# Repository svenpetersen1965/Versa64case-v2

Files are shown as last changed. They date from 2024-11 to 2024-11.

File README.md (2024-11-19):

# Versa64case-v2
The Versa64case v2 is my 2nd approach to a 3D printed case for the <a href="https://github.com/bwack/Versa64Cart">Versa64card by bwack</a>. 

The goal was to develope a case, that is less complicated than the first case from 2019 and only consist of two parts while offering fill access to the DIP-switch and the configuration jumpers. Also, a closed version without this access is required, in case no configuration change is desired or for the <a href="https://github.com/svenpetersen1965/Epyx-FastLoad">Epxy Fast Load cartridge</a>.

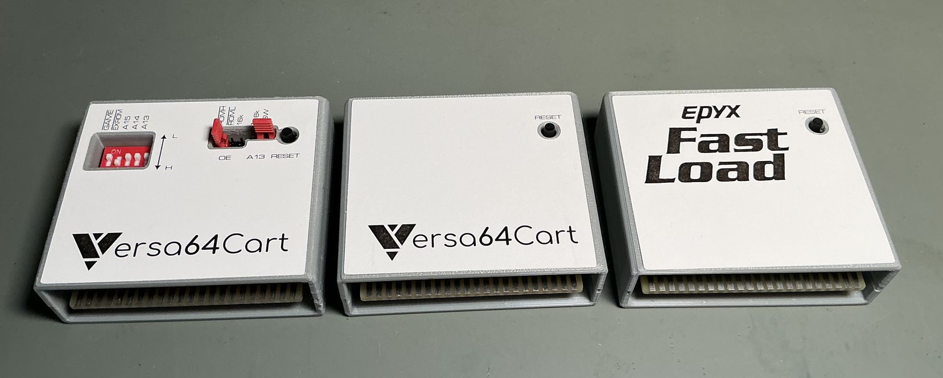
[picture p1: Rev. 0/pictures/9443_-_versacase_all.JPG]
Versa64case


# Versions

1. <b>Versa64case With Full Configuration Access</b><br>
This version allows to access the DIP-switch and the configuration jumpers.

2. <b>Versa64case Without Configuration Access</b><br>
This version does not allow changing the configuration of the Versa64cart without opening the case, which might be a desirable option for some projects.

# Project Documentation

Please consider reading the <a href="https://github.com/svenpetersen1965/Versa64case-v2/blob/main/Rev.%200/pdf/Versa64caseV2_Rev0.pdf">Documentation</a>.

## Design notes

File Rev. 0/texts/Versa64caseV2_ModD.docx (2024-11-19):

Versa64case v2 Rev. 0

Module description

# 1. Introduction

The Versa64case v2 is my 2nd approach to a 3D printed case for the Versa64card by bwack. The Versa64cart can be found here: https://github.com/bwack/Versa64Cart

The goal was to develop a case, that is less complicated than the first case from 2019 and only consist of two parts while offering fill access to the DIP-switch and the configuration jumpers. Also, a closed version without this access is required, in case no configuration change is desired or for the Epxy Fast Load cartridge (which can be found here: https://github.com/svenpetersen1965/Epyx-FastLoad).


Figure 1: All versions of the case with labels

# 2. Versa64case With Full Configuration Access

This version allows to access the DIP-switch and the configuration jumpers. For the easiest way to change the configuration, it is best to use jumpers with a “handle”, which protrude over the case. They are available from multiple sources and manufacturers (e.g. Reichelt MPE 149-4-002-F0 or Ali Express product URL (https://de.aliexpress.com/item/1005006390258256.html?channel=twinner)).

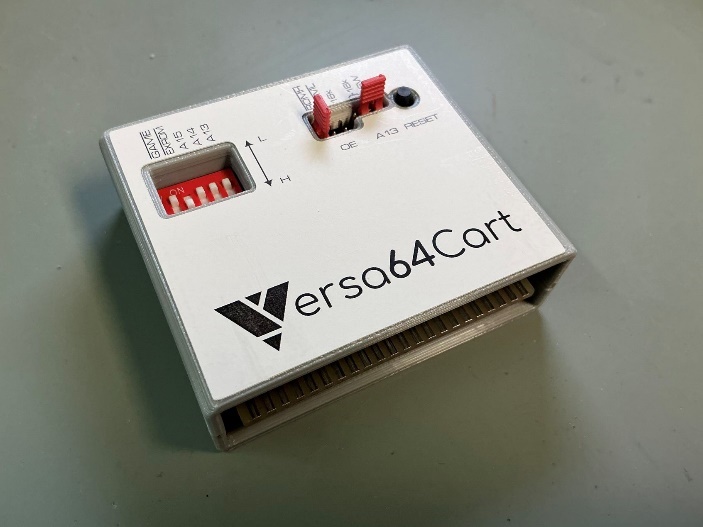
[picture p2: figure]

Figure 2: Version with full configuration access

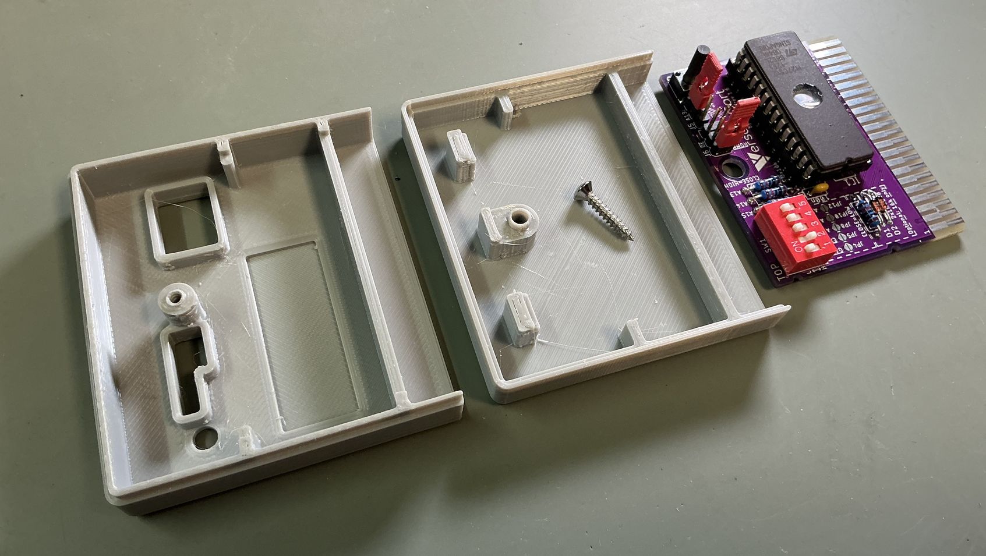
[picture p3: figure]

Figure 3: Version with full configuration access (internal)

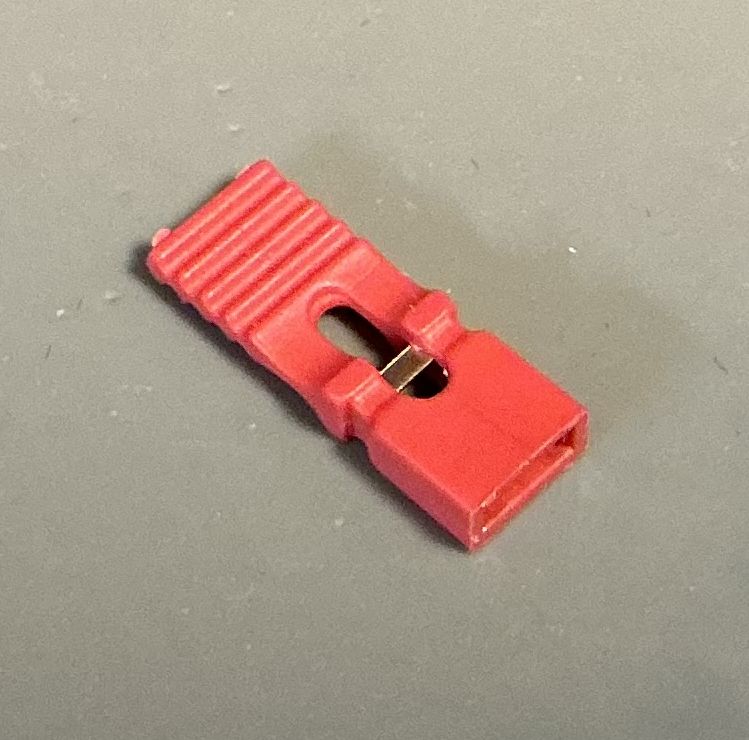
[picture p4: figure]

Figure 4: Jumper with handle

# 3. Versa64case Without Configuration Access

This version does not allow changing the configuration of the Versa64cart without opening the case, which might be a desirable option for some projects.

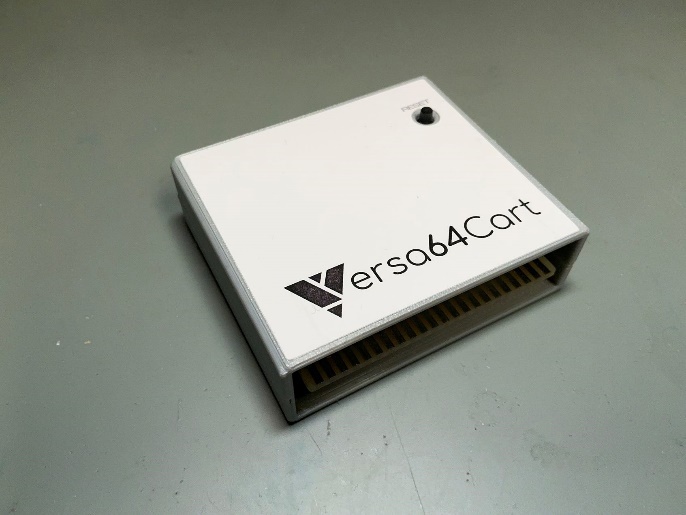
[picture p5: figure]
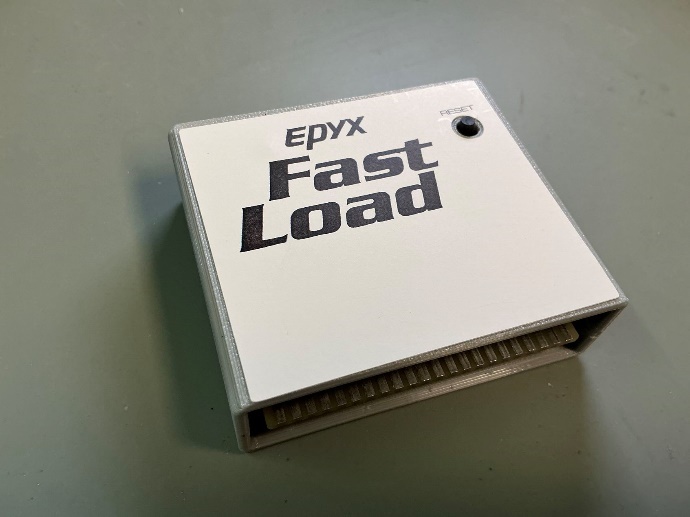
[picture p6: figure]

Figure 5: Versa64Case without configuration access

The Epyx FastLoad cartridge, which was mentioned before, does not require accessing any configuration and has the same form factor of the Versa64Cart. There is an extra version of label for it.

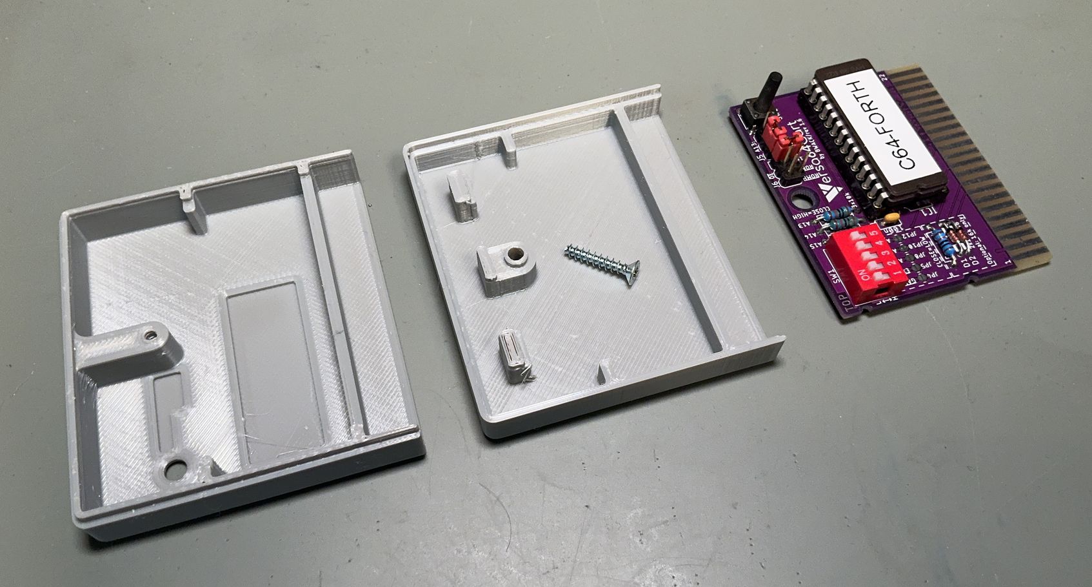
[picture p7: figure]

Figure 6: Closed version without configuration access

In case short pin headers and (open) jumpers are used, they will fit under the case.

# 4. The Reset Switch

Originally, the reset switch on the Versa64card has a height of 7mm. For this case a TACT switch with a total height of 11.0mm -12.5mm is recommended. The distance between the top surface of the case and the top surface of the PCB is 10.8 mm.

# 5. Recommended screws

Countersunk, self-tapping screws with a total length of 13.0mm to 16.0mm and a diameter of 2.9mm (C2.9 x 13 or C2.9 x 16) are recommended. E.g. DIN 7982 or DIN 7983.

# 6. Revision History

## 6.1. Rev. 0

- Working prototype

Versa64caseV2_ModD.docx 19.11.2024 17:24 Drafted by Sven Petersen Page 2 of 2 Doc.-No.: 216-6-01-00

Versa64caseV2_ModD.docx 19.11.2024 17:24 Drafted by Sven Petersen Page 1 of 1 Doc.-No.: 216-6-01-00

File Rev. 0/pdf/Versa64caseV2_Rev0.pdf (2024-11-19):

# Project Documentation

## Versa64case v2

## Project number: 216

## Revision: 0

## Date: 19.11.2024

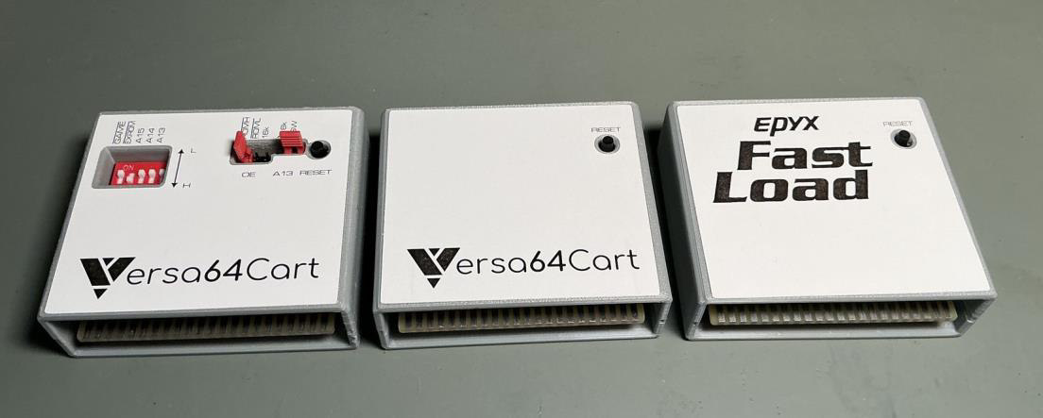
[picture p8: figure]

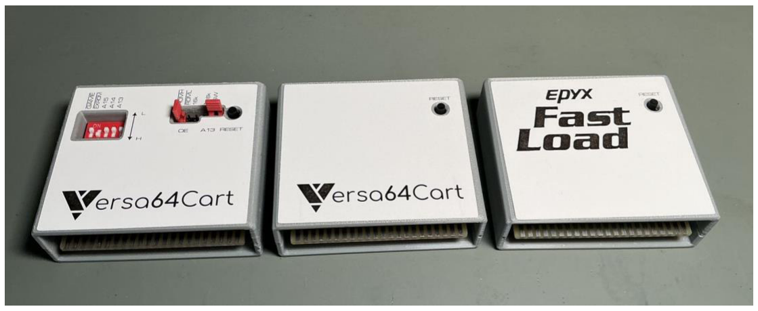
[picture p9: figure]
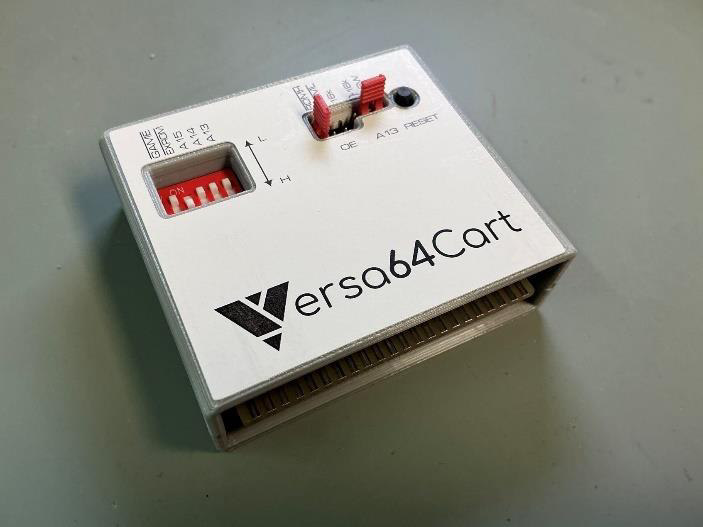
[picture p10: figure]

Versa64caseV2_ModD.docx | | 19.11.2024 17:24
Drafted by Sven Petersen | Page 1 of 4 | Doc.-No.: 216-6-01-00

### Versa64case v2 Rev. 0

### Module description

## 1. Introduction

The Versa64case v2 is my 2nd approach to a 3D printed case for the Versa64card by bwack. The Versa64cart can be found here: https://github.com/bwack/Versa64Cart

The goal was to develop a case, that is less complicated than the first case from 2019 and only consist of two parts while offering fill access to the DIP-switch and the configuration jumpers. Also, a closed version without this access is required, in case no configuration change is desired
or | for | the | Epxy | Fast | Load | cartridge | (which | can | be | found | here:
https://github.com/svenpetersen1965/Epyx-FastLoad).

Figure 1: All versions of the case with labels

## 2. Versa64case With Full Configuration Access

This version allows to access the DIP-switch and the configuration jumpers. For the easiest way to change the configuration, it is best to use jumpers with a “handle”, which protrude over the case. They are available from multiple sources and manufacturers (e.g. Reichelt MPE 149-4-002-F0 or Ali Express product URL). (https://de.aliexpress.com/item/1005006390258256.html?channel=twinner)

Figure 2: Version with full configuration access

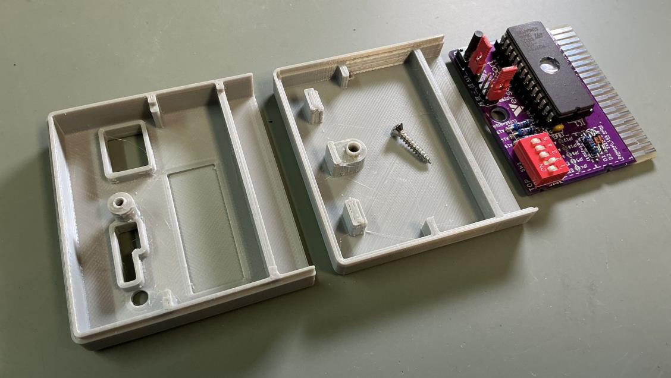
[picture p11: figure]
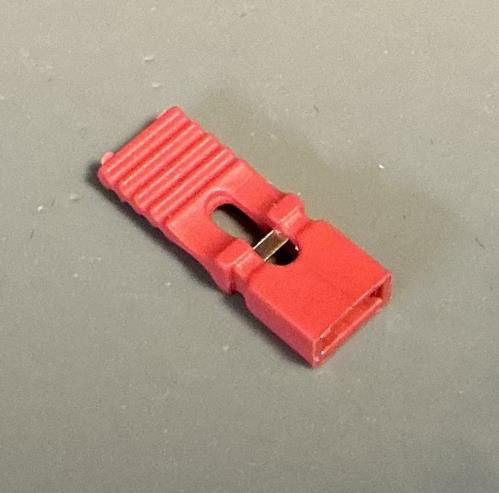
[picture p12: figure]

Drafted by Sven Petersen | Page 2 of 4 | Doc.-No.: 216-6-01-00

Figure 3: Version with full configuration access (internal)

Figure 4: Jumper with handle

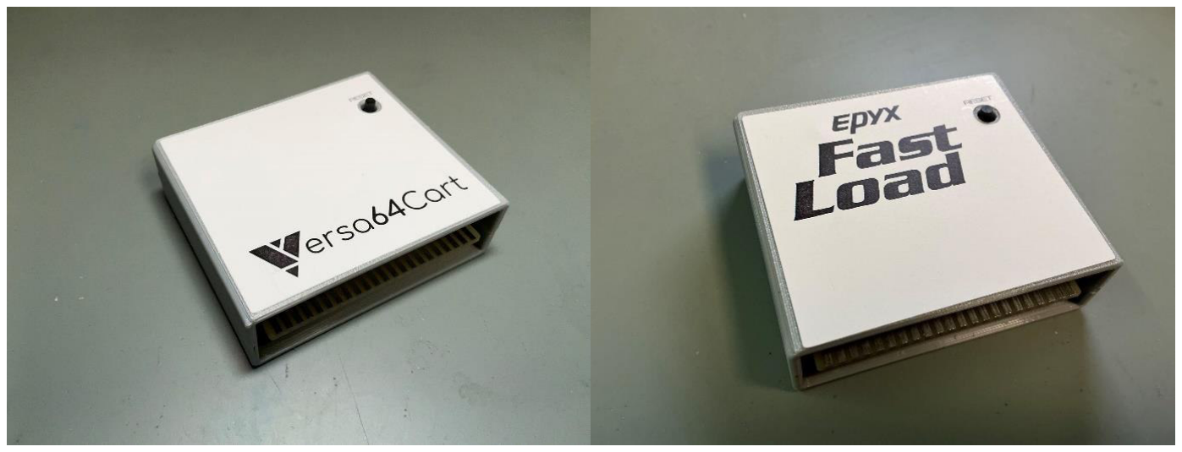
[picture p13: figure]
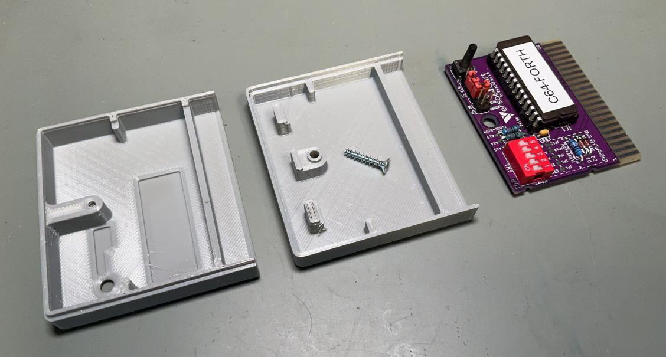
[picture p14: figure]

Drafted by Sven Petersen | Page 3 of 4 | Doc.-No.: 216-6-01-00

## 3. Versa64case Without Configuration Access

This version does not allow changing the configuration of the Versa64cart without opening the case, which might be a desirable option for some projects.

Figure 5: Versa64Case without configuration access

The Epyx FastLoad cartridge, which was mentioned before, does not require accessing any configuration and has the same form factor of the Versa64Cart. There is an extra version of label for it.

Figure 6: Closed version without configuration access

In case short pin headers and (open) jumpers are used, they will fit under the case.

## 4. The Reset Switch

Originally, the reset switch on the Versa64card has a height of 7mm. For this case a TACT switch with a total height of 11.0mm -12.5mm is recommended. The distance between the top surface of the case and the top surface of the PCB is 10.8 mm.

## 5. Recommended screws

Countersunk, self-tapping screws with a total length of 13.0mm to 16.0mm and a diameter of 2.9mm (C2.9 x 13 or C2.9 x 16) are recommended. E.g. DIN 7982 or DIN 7983.

Drafted by Sven Petersen | Page 4 of 4 | Doc.-No.: 216-6-01-00

## 6. Revision History

### 6.1. Rev. 0

- Working prototype

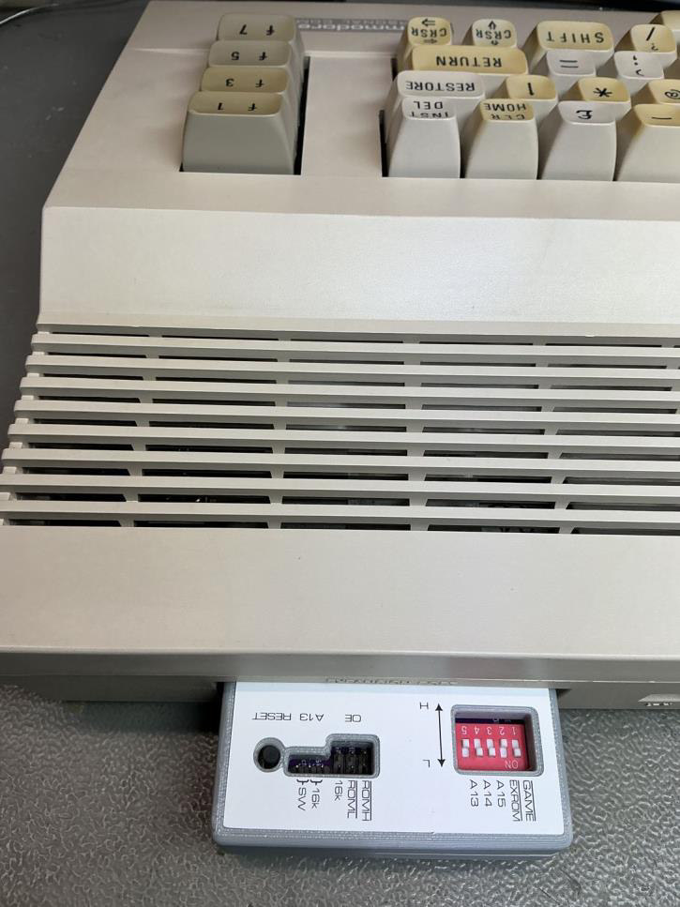
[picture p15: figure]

Versa64caseV2_Test.docx | | 19.11.2024 19:34
Drafted by Sven Petersen | Page 1 of 3 | Doc.-No.: 216-6-02-00

### Versa64case v2 Rev. 0

### Test Description description

## 1. Devices under Test

- Versa64case v2 with accessible configuration with Versa64Cart and long jumpers
- Versa64case v2 without accessible configuration with Versa64Cart and short jumpers
- Versa64case v2 without accessible configuration with Epyx Fast Load

## 2. Test Execution

### 2.1. Mountability

- Both, the Versa64cart and the Epyx FastLoad cartridge PCBs fit inside the cases.
- The short jumpers do not collide with the top shell
- The screw (16mm and 13mm) fits into the case and reliably holds both halves together

### 2.2. Fits into the Expansion Ports

Both versions of the case are tested with different computers

- The cases fit into the expansion port of the C64 bread bin (Figure 3)
- The cases fit into the expansion port of the C64C (Figure 2)
- The cases fit into the expansion port of the C128 (Figure 1)

Figure 1: Test with C128

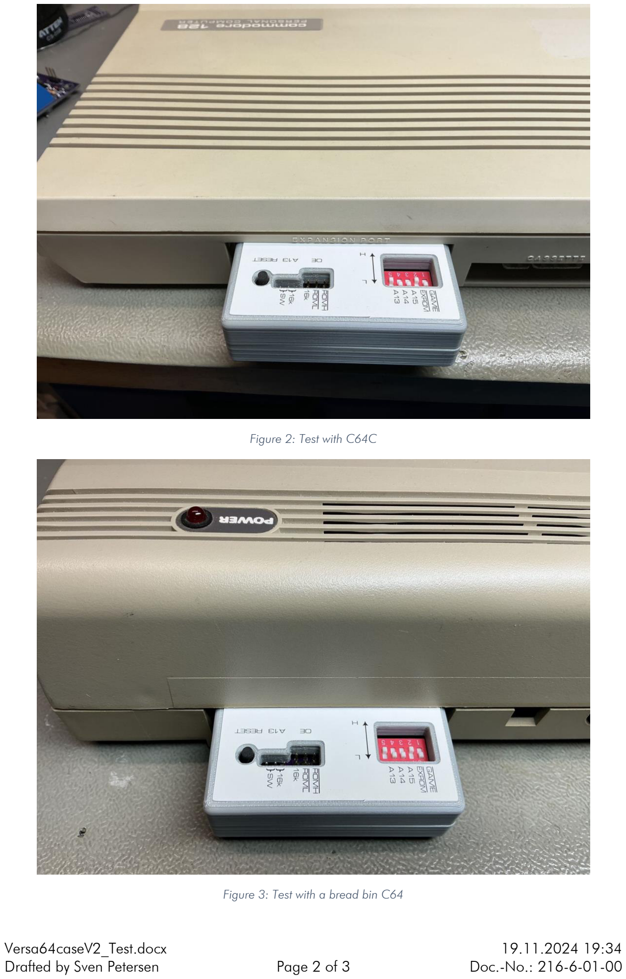
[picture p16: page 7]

Versa64caseV2_Test.docx | | 19.11.2024 19:34
Drafted by Sven Petersen | Page 2 of 3 | Doc.-No.: 216-6-01-00

Figure 2: Test with C64C

Figure 3: Test with a bread bin C64

Versa64caseV2_Test.docx | | 19.11.2024 19:34
Drafted by Sven Petersen | Page 3 of 3 | Doc.-No.: 216-6-01-00

## Conclusion

The Versa63case v2 works/fits with all known configuration.

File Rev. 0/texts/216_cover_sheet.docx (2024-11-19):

Project Documentation

Versa64case v2

Project number: 216

Revision: 0

Date: 19.11.2024


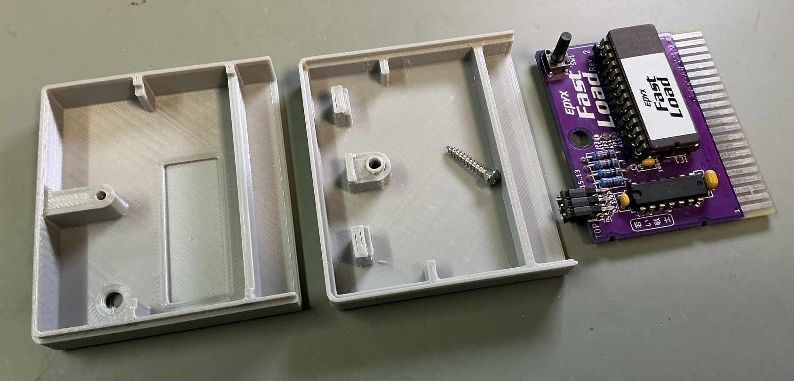
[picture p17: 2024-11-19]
Rev. 0/pictures/9254_-_versacase_no_acc_EpyxFL.JPG

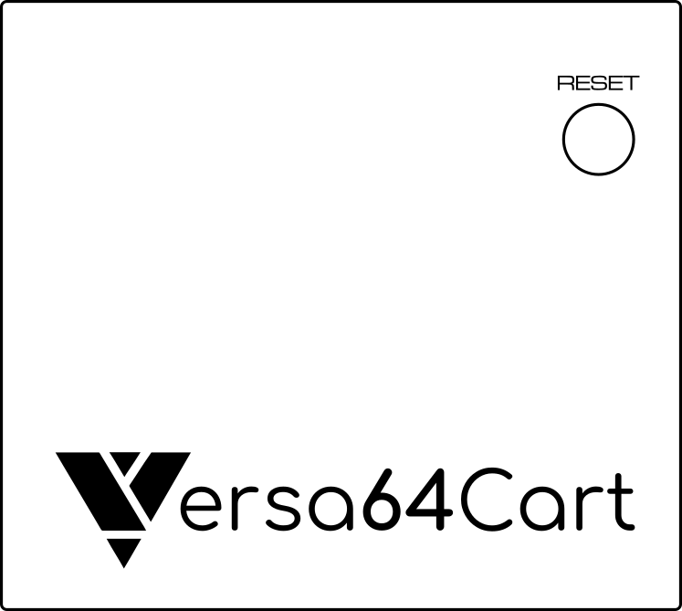
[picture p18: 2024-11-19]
Rev. 0/label/Versa64case_closed_label.png

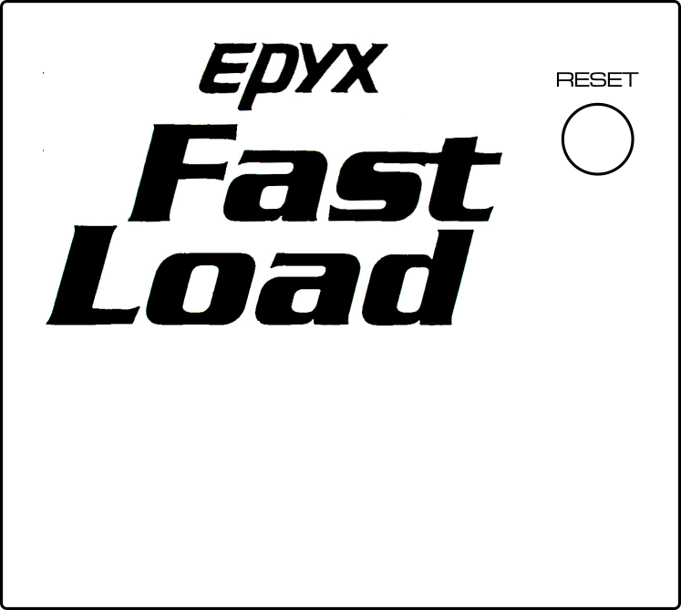
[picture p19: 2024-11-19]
Rev. 0/label/Versa64case_Epyx_FastLoad_label.png

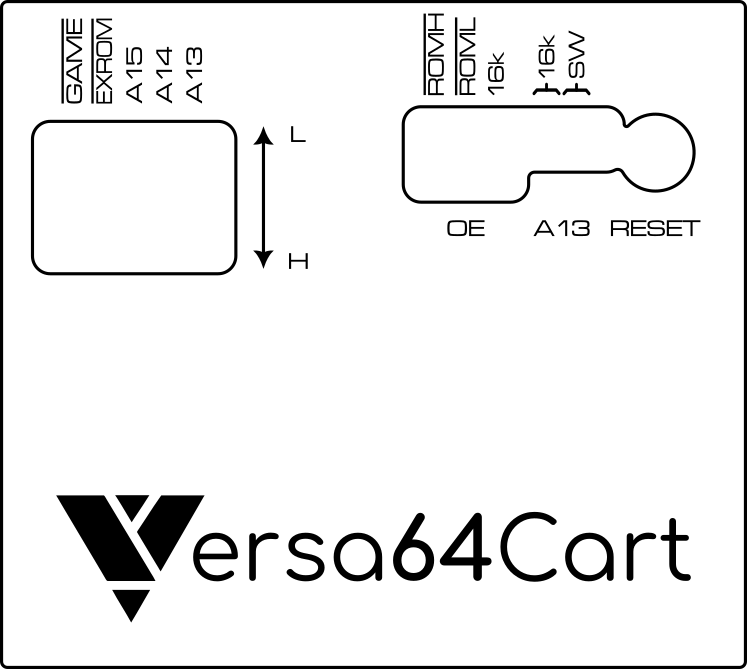
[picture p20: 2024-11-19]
Rev. 0/label/Versa64case_label.png

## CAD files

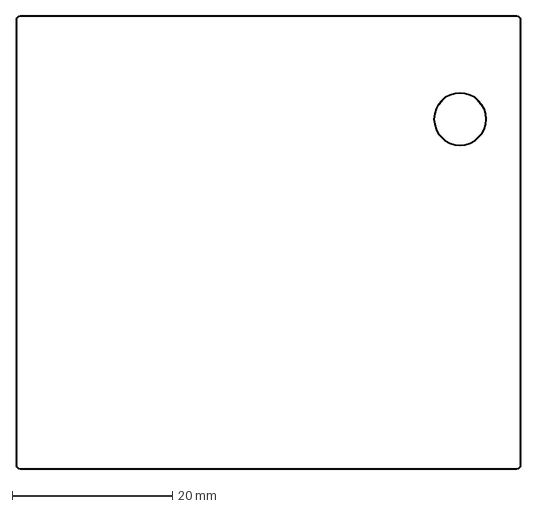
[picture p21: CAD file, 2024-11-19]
Rev. 0/label/outline_closed.dxf
63.0 x 56.4 mm

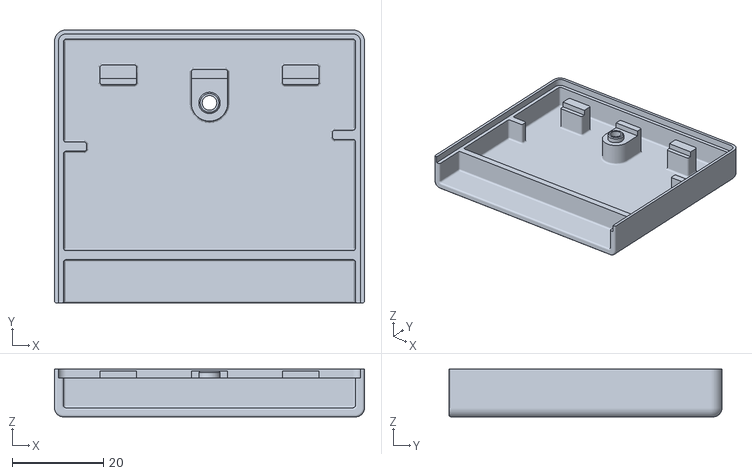
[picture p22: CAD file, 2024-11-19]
Rev. 0/stl/versa64case_v2_bottom_closed.stl
68.0 x 59.9 x 10.5

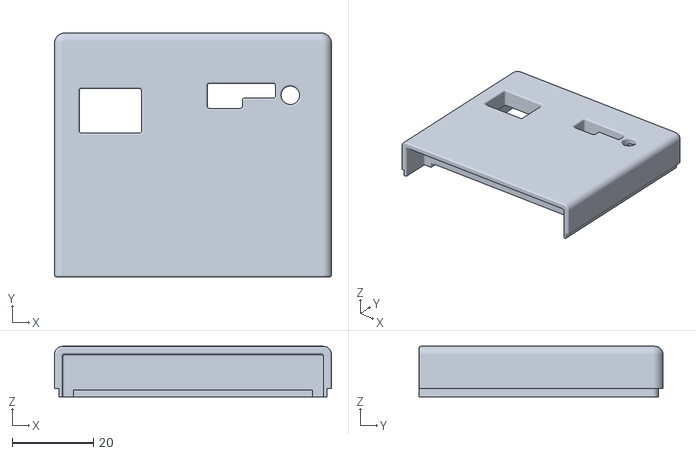
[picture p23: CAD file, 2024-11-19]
Rev. 0/stl/Versa64case_v2_top.stl
68.0 x 59.9 x 12.4

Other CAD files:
Rev. 0/stl/versa64case_v2_bottom.stl
Rev. 0/stl/Versa64case_v2_top_closed.stl
Rev. 0/fusion360/versa64case_2_0 v18.f3d
Rev. 0/fusion360/versa64case_2_0_closed v9.f3d

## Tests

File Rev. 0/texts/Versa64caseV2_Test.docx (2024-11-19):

Versa64case v2 Rev. 0

Test Description description

# 1. Devices under Test

- Versa64case v2 with accessible configuration with Versa64Cart and long jumpers
- Versa64case v2 without accessible configuration with Versa64Cart and short jumpers
- Versa64case v2 without accessible configuration with Epyx Fast Load

# 2. Test Execution

## 2.1. Mountability

- Both, the Versa64cart and the Epyx FastLoad cartridge PCBs fit inside the cases.
- The short jumpers do not collide with the top shell
- The screw (16mm and 13mm) fits into the case and reliably holds both halves together

## 2.2. Fits into the Expansion Ports

Both versions of the case are tested with different computers

- The cases fit into the expansion port of the C64 bread bin (Figure 3)
- The cases fit into the expansion port of the C64C (Figure 2)
- The cases fit into the expansion port of the C128 (Figure 1)

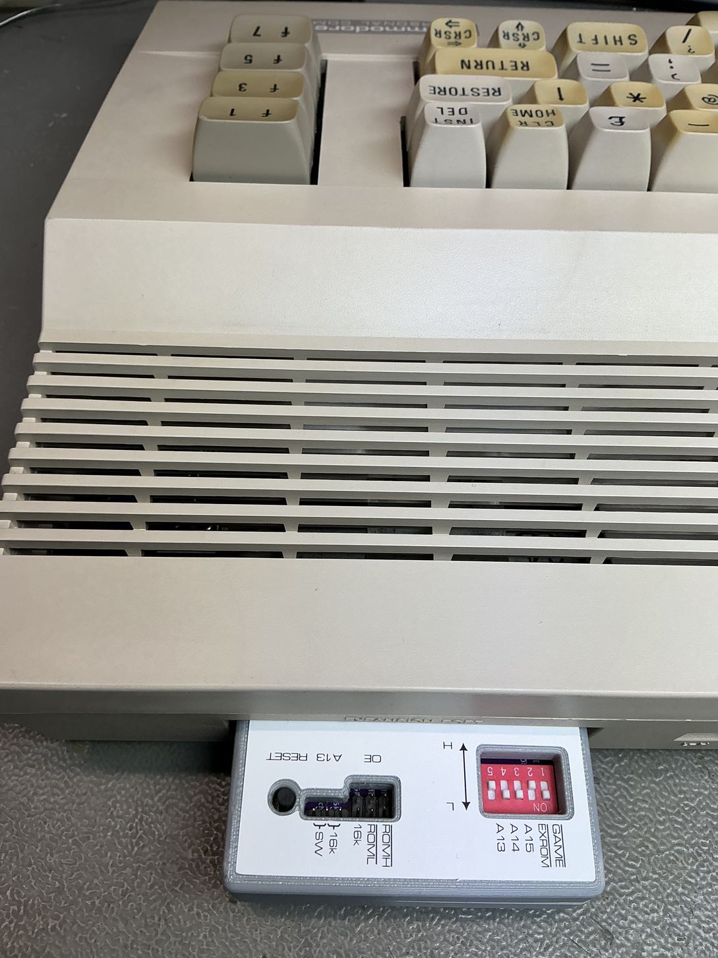
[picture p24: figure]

Figure 1: Test with C128

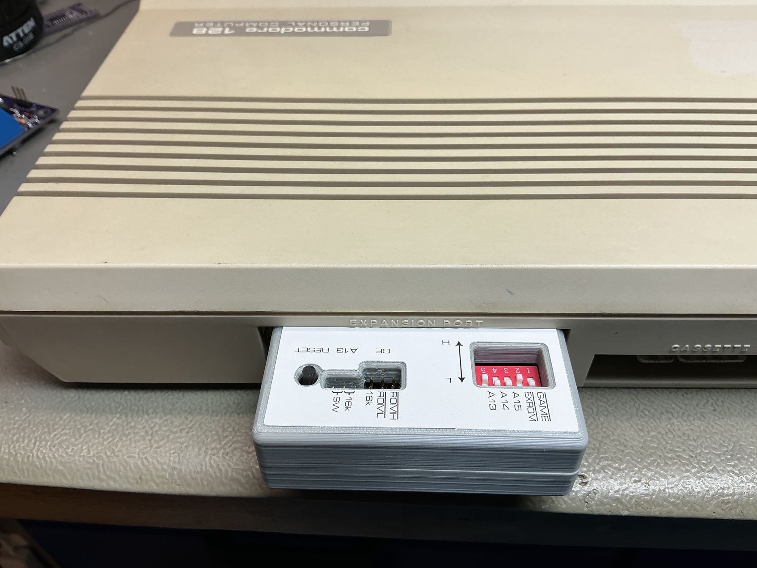
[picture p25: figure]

Figure 2: Test with C64C

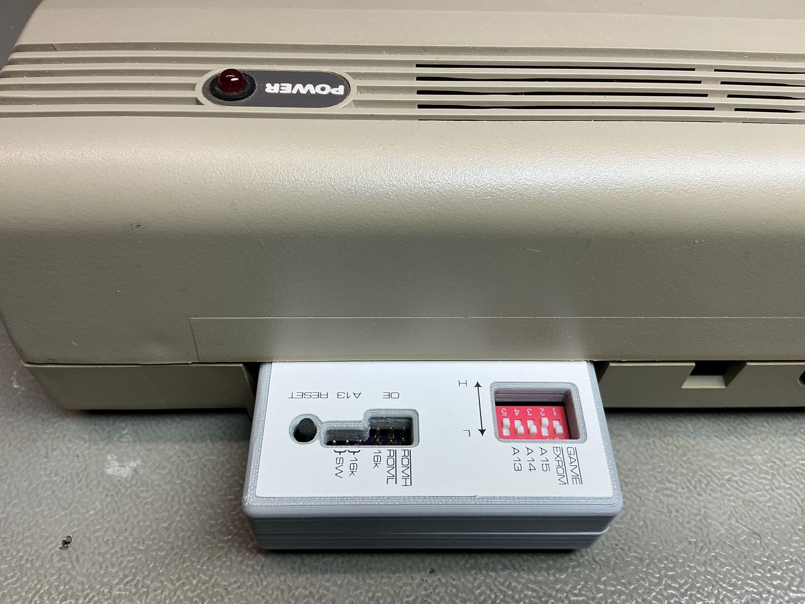
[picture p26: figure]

Figure 3: Test with a bread bin C64

# Conclusion

The Versa63case v2 works/fits with all known configuration.

Versa64caseV2_Test.docx 19.11.2024 19:34 Drafted by Sven Petersen Page 2 of 2 Doc.-No.: 216-6-01-00

Versa64caseV2_Test.docx 19.11.2024 19:34 Drafted by Sven Petersen Page 1 of 1 Doc.-No.: 216-6-02-00
